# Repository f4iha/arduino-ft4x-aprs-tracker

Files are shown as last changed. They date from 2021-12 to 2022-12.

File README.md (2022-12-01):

# GPS tracker on Ham radio APRS network

## The projet

This project is inspired by Valentin work with his APRS tracker using a DRA818 https://github.com/valentintintin/arduino-tracker-aprs-dra818. 

I initially wanted to a Baofeng UV5R as TX, finally I decided to use a Yaesu FT4X. Also I added the possibility to change after the startup which APRS symbol is used. 

### Hardware parts used
- Arduino [Nano](https://store.arduino.cc/arduino-nano)
- GPS Module ([NEO 6M](https://www.amazon.fr/NEO-6M-GPS-module-puissance-GY-GPS6MV2/dp/B01ICYA4QU))
- few electronics components (resistor, capacitor, 2N2222, variable resistor, LEDs and push button)

### Software parts used
- [PlatformIO](https://platformio.org/)
- [QAPRS lib](https://bitbucket.org/valentintintin/arduinoqaprs/) from Lukasz SQ5RWU, forked by Valentin to add PWM
- [TinyGPS+ lib](http://arduiniana.org/libraries/tinygpsplus/)
- [EasyButton](https://github.com/evert-arias/EasyButton) from Evert Arias 

### The circuit

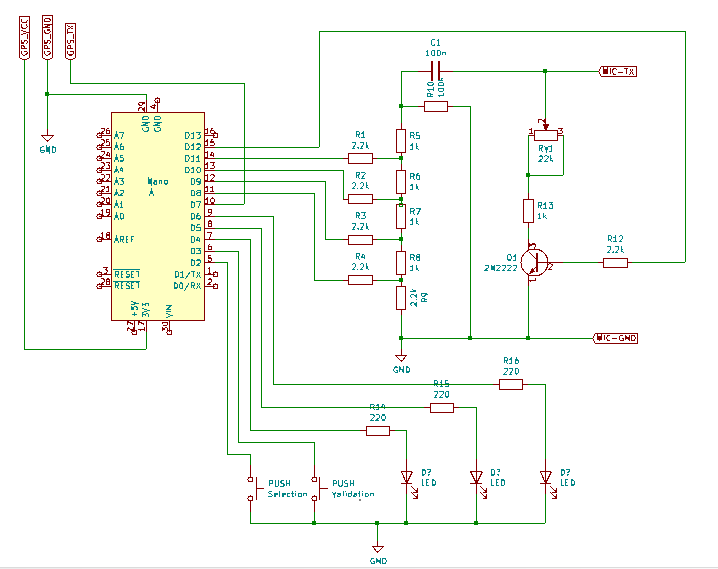
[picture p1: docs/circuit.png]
The entire circuit


The Kicad file is available in the _electronic_ folder

### The Arduino program

The project has one main function : **send its GPS coordinate on ham radio APRS network** using a FT4X as transmitter.

### Compile and run

1. Install [PlatformIO](https://docs.platformio.org/en/latest/installation.html)
2. Run `git clone https://github.com/f4iha/arduino-ft4x-aprs-tracker && cd ardu-aprs-tracker`
3. Run `mkdir lib; cd lib; git clone https://bitbucket.org/valentintintin/arduinoqaprs/; cd ..` to download the updated version of ArduinoQAPRS
4. You have to uncomment `APRS_HW_TYPE_R2R` and comment all the others in `.piolibdeps/ArduinoQAPRS/ArduinoQAPRS.h`
5. Update with your callsign in _main.cpp_ file and adjust if needed the used APRS symbol (see section **Change the APRS symbol** below for more details)
6. Plug your Arduino nano
7. Run `pio run --target upload -e nanoprod`

##### Notes

- The QAPRS lib uses a **R2R resistor network** to generate the sound signal

#### Program flow

1. At the startup, the Arduino will ask using 3 LEDs which APRS symbol will be used (car, bike, jogger)
    - If you want to start in test mode (no guard for GPS fix or TX rate), keep pressed the "validation" button at startup
2. Change and validate the symbol to be used
3. If the GPS is locked AND time between TX is reached ==> send the new location. The time between TX is defined by the speed and two affine functions.
4. Keep pressed the "validation" button to send your position (if GPS fix) manually

##### Change the APRS symbol

The APRS symbol are configured via the 2 variables aprsMarks and aprsTypes respectively linked. Selecting _velo_ (french for bike) will use the character _b_ for the symbol
```c
String aprsMarks[] = { "voiture", "velo", "pieton" };
char aprsTypes[] = ">b[";
```

This [aprs.net page](http://www.aprs.net/vm/DOS/SYMBOLS.HTM) is giving a good list of the main symbol.

### The PCB

I produce a PCB using through-hole components. This is available in the _pcb_  folder. There are also 3 pin (J8, J9 and J10) which can be used the PTT and the signal needs to remain separated.

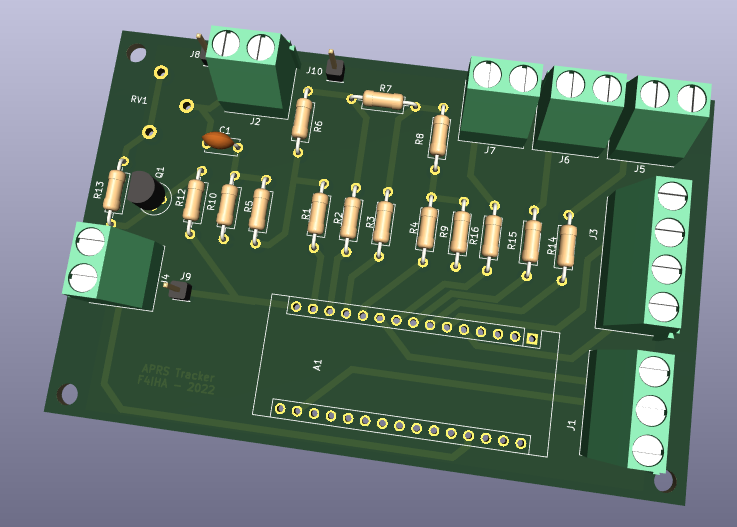
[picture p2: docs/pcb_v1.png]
Through-hole PCB


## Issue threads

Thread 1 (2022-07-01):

Problème avec des lat/lon négatives

rhaamo, 2022-07-01:
Après debug avec un autre radioamateur, qui se trouve avoir une LNG négative, on a du changer la ligne suivante:
https://github.com/f4iha/arduino-ft4x-aprs-tracker/blob/main/src/APRS.cpp#L181

en:
```
stringPaddingf(fabsf(lngDegMin), 5, &packetBuffer);
```

`fabsf` seulement a l'insertion pour passer en positif.

Dans son cas ça fonctionne.

Je soupçonne qu'il faille faire pareil pour la LAT a la ligne 169

f4iha, 2022-07-02:
Merci @rhaamo pour le retour.
Je viens de modifier le code. Impossible d'avoir une situation réelle pour moi donc je me base sur le retour.
J'ai aussi remarqué une valeur incorrecte pour la latitude à la ligne 174 https://github.com/f4iha/arduino-ft4x-aprs-tracker/commit/885183f50143717b1980dde922449a3f40805ddc

Si aucun autre changement n'a été effectué, je fusionnerais les changements avec le main

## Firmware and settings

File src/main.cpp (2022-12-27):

#include <Arduino.h>
#include "Utils.h"
#include "GPS.h"
#include "APRS.h"
#include <EasyButton.h>

#define APRS_COMMENT " send from  https://github.com/f4iha/arduino-ft4x-aprs-tracker"
#define BUTTON_SELECT 2
#define BUTTON_VALID 3
#define TX_GPS 7 // from GPS to Arduino
#define PTT_OUT 12

char CALL[] = "CALLSIGN";
char TO_CALL[] = "APFD01"; // AP = AP Packet + F = France + D01 = department 01 in France
uint8_t TO_CALL_ID = '0';
char RELAYS[]  = "WIDE1-1,WIDE2-2";
String aprsMarks[] = { "voiture", "velo", "pieton" };
char aprsTypes[] = ">b[";
uint8_t callSsidCar = '9'; // car
uint8_t callSsidWalk = '7'; // pieton, velo

bool isTestMode = IS_TEST_MODE;

bool valid_state = false;
int stepMark = 0;
int loopInitMode = 0;
int maxStepMark = 3;
int pinLed =4 ;
int selectedPin = pinLed;

GPS gps(TX_GPS);
APRS aprs(&gps, PTT_OUT);
EasyButton button_select(BUTTON_SELECT);
EasyButton button_valid(BUTTON_VALID);

void setup() {
    Serial.begin(115200);
    Serial.println("Starting ...");
    
    pinMode(BUTTON_SELECT, INPUT_PULLUP);  
    pinMode(BUTTON_VALID, INPUT_PULLUP); 

    for (int tmpLed = pinLed; tmpLed < (pinLed + maxStepMark); tmpLed++){
        pinMode(tmpLed,OUTPUT); 
    }

    button_select.begin();  
    button_valid.begin();
    
    button_valid.read();

    if (button_valid.isPressed()) {
        isTestMode = !isTestMode;
        Serial.println("Test mode: ");
        Serial.println(isTestMode);
    }

    aprs.init(CALL, callSsidCar, TO_CALL, TO_CALL_ID, RELAYS);
    aprs.setComment(APRS_COMMENT);
    aprs.setPinLed(pinLed);

    button_valid.onPressedFor(3000, []() {
        Serial.println("TX Forced");
        blink(5, selectedPin, 50);
        if (valid_state == true){
            aprs.sendIfPossible(isTestMode, true, selectedPin);
        }
    });

    digitalWrite(pinLed,HIGH);
}

void loop() {
    if(valid_state == false){
        button_valid.read();
        button_select.read();
        // if time spend in this selection mode around 20s, we activate with the first mode
        if(button_valid.isPressed() || loopInitMode > 100){
            valid_state = true;
            selectedPin = stepMark + pinLed;
            blink(10, selectedPin, 50);
            Serial.print("Selected ");
            Serial.println(aprsMarks[stepMark]);
            aprs.setSymbol(aprsTypes[stepMark]);
            if (stepMark == 0){
                aprs.updateSSID(CALL, callSsidCar);
            }else{
                aprs.updateSSID(CALL, callSsidWalk);
            }
        }
        if(button_select.isPressed()){
            digitalWrite(stepMark+pinLed,LOW); 
            stepMark++;
            if (stepMark == maxStepMark){
                stepMark = 0;
            }
            Serial.print("Displaying ");
            Serial.println(aprsMarks[stepMark]);
            digitalWrite(stepMark+pinLed,HIGH); 
        }
        delay(200);
        loopInitMode++;
    } else {
        button_valid.read();
        aprs.sendIfPossible(isTestMode, isTestMode, selectedPin);     
    }
}

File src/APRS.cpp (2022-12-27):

#include <ArduinoQAPRS.h>
#include "APRS.h"
#include "Utils.h"

#define TIME_TOGGLE_PTT 500

APRS::APRS(GPS *gps, uint8_t txPin) : gps(gps), txPin(txPin) {
    pinMode(txPin, OUTPUT);
    packetBuffer.reserve(255);
}


void APRS::print_uint64_t(uint64_t num) {

  char rev[128]; 
  char *p = rev+1;

  while (num > 0) {
    *p++ = '0' + ( num % 10);
    num/= 10;
  }
  p--;
  /*Print the number which is now in reverse*/
  while (p > rev) {
    Serial.print(*p--);
  }
}

void APRS::init(char *call, uint8_t callId, char *toCall, uint8_t toCallId, char *relays) {
    QAPRS.init(0, 0, call, callId, toCall, toCallId, relays);
}

bool APRS::txToRadio() {
    blinkAll(3, this->pinLed , 250, 4);
    Serial.println("TX ...");

    digitalWrite(LED_BUILTIN, HIGH);
    digitalWrite(txPin, HIGH);
    delay(TIME_TOGGLE_PTT);
 
    delay(500);

    Serial.println("Packet sending");

    bool qaprsOk = QAPRS.sendData((char *) packetBuffer.c_str()) == QAPRSReturnOK;

    Serial.println("Packet sent");

    delay(500);

    digitalWrite(LED_BUILTIN, LOW);
    digitalWrite(txPin, LOW);
    delay(TIME_TOGGLE_PTT);
    
    if (qaprsOk) {
        Serial.println("TX OK");
    } else {
        Serial.println("TX FAILED");
    }

    return qaprsOk;
}

void APRS::setComment(String comment) {
    this->comment = comment;
}

bool APRS::sendIfPossible(bool forceGps, bool forceTx, int selectedBlinkPin) {
    if (gps->getData() || forceGps) {
        if (millis() - lastTx >= (uint32_t) 1000 * getTimeSecondsForGivenSpeed() || forceTx) {
            if (sendPosition()) {
                blink(2, selectedBlinkPin);
                lastTx = millis();
                lastSpeed = gps->gps.speed.kmph();
                return true;
            }
        }
        blink(1, selectedBlinkPin);

        Serial.print("Next: "); 
        print_uint64_t(abs(getTimeSecondsForGivenSpeed() - ((millis() - lastTx) / 1000)));
        Serial.print("/"); 
        print_uint64_t(getTimeSecondsForGivenSpeed());
        Serial.println();

        return false;
    } else {
        lastTx = 0;
        lastSpeed = 0;
        blink(5);
        return false;
    }
}

#pragma clang diagnostic push
#pragma ide diagnostic ignored "hicpp-signed-bitwise"
long APRS::readVccAtmega() {
    long result;  // Read 1.1V reference against AVcc
    ADMUX = _BV(REFS0) | _BV(MUX3) | _BV(MUX2) | _BV(MUX1);
    delay(2);             // Wait for Vref to settle
    ADCSRA |= _BV(ADSC);  // Convert
    while (bit_is_set(ADCSRA, ADSC));
    result = ADCL;
    result |= ADCH << 8;
    result = 1126400L / result;  // Back-calculate AVcc in mV
    return result;
}
#pragma clang diagnostic pop

uint16_t APRS::getTimeSecondsForGivenSpeed() {
    float speed = gps->gps.speed.kmph();
    if (speed >= 20) {
        return -0.1 * speed + 42;
    } else if (speed >= 5) {
        return -11 * speed + 230;
    } else if (lastSpeed >= 20 || lastTx == 0) {
        return 0;
    } else {
        return 100;
    }
}

float APRS::convertDegMin(float decDeg) {
    float DegMin;

    int intDeg = (int) decDeg;               // partie entière
    decDeg -= (float) intDeg;                  // partie décimale
    decDeg *= 60;                      // décimale * 60
    DegMin = (float) (intDeg * 100) + decDeg;  // entière * 100 + décimale

    return DegMin;
}

void APRS::stringPadding(int number, byte width, String *dest) {
    int temp = number;
    if (!temp) {
        temp++;
    }

    for (int i = 0; i < width - (log10(temp)) - 1; i++) {
        dest->concat('0');
    }
    dest->concat(number);
}

void APRS::stringPaddingf(float number, byte width, String *dest) {
    float temp = number;
    if (temp == 0) {
        temp++;
    }

    for (int i = 0; i < width - (log10(temp)) - 1; i++) { // NOLINT(performance-type-promotion-in-math-fn)
        dest->concat('0');
    }
    dest->concat(number);
}

void APRS::buildPacket() {
    auto lat = (float) gps->gps.location.lat();
    auto lng = (float) gps->gps.location.lng();
    float latDegMin = convertDegMin(lat);
    float lngDegMin = convertDegMin(lng);

    packetBuffer.remove(0, packetBuffer.length());

    // Start coordinates
    packetBuffer += '!';

    // Latitude
    stringPaddingf(fabsf(latDegMin), 4, &packetBuffer);
    // Determine N or S
    if (latDegMin >= 0) {
        packetBuffer += 'N';
    } else if (latDegMin < 0) {
        packetBuffer += 'S';
    }

    // Separator
    packetBuffer += '/';

    // Longitude
    stringPaddingf(fabsf(lngDegMin), 5, &packetBuffer);
    // Determine E or W
    if (lngDegMin >= 0) {
        packetBuffer += 'E';
    } else if (lngDegMin < 0) {
        packetBuffer += 'W';
    }

    // Symbol car, walk, bike...
    packetBuffer += this->symbol;
    
    // North orientation
    stringPadding((int) gps->gps.course.deg(), 3, &packetBuffer);
    // Separator
    packetBuffer += '/';
    // Speed
    stringPadding((int) gps->gps.speed.knots(), 3, &packetBuffer);
    // Altitude
    packetBuffer += "/A=";
    stringPadding((int) gps->gps.altitude.feet(), 6, &packetBuffer);
    // Voltage
    packetBuffer += "/V=";
    packetBuffer += (float) readVccAtmega() / 1000.f;
    // Accuracy
    packetBuffer += " HDOP=";
    packetBuffer += (int) gps->gps.hdop.hdop();
    // Comment
    if (comment.length()) {
        packetBuffer += comment;
    }

    Serial.print("Packet : ");
    Serial.println(packetBuffer);
}

bool APRS::sendPosition() {
    buildPacket();
    return txToRadio();
}


void APRS::setSymbol(char symbol) {
    this->symbol = symbol;
}

void APRS::setPinLed(int pinLed){
    this->pinLed = pinLed;
}

void APRS::updateSSID(char *call, uint8_t ssid){
    QAPRS.setFromAddress(call, ssid);
}

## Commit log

2021-12-27 Migration kicad5 to Kicad6
    [ardu-aprs-tracker.kicad_sch, ardu-aprs-tracker.sch]
2022-06-29 Adjusting delays for the button selection
2022-07-02 Fix wrong cardinal position for negative latitudes
    [APRS.cpp]
2022-07-20 Add blink all leds when sending APRS message
2022-07-20 Fixing bug on LEDs blinking during TX
    [Utils.cpp, main.cpp]
2022-11-11 Push updated schematics
    [ardu-aprs-tracker.kicad_sch]
2022-11-11 Add PCB
    [ardu-aprs-tracker-pcb.kicad_pcb, ardu-aprs-tracker-pcb.kicad_sch]
2022-12-01 Add documentation related to PCB
2022-12-01 Add pcb kicad picture
2022-12-27 Add management of the correct SSID (car or walk)
    [APRS.cpp, main.cpp]
